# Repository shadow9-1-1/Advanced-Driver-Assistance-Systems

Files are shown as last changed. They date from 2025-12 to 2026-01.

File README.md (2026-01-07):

# Advanced-Driver-Assistance-Systems
Embedded Systems project that required to design and implement common ADAS (Advanced Driver-Assistance Systems) shipped in modern cars and EVs (Electric Vehicles).

---
1) Based on the input from the driver on the acceleration pedal, the microcontroller generates the corresponding output to the motor driving system to move the car. The vehicle speed is displayed on the LCD. When the brake pedal is pressed, the car decelerates until it stops regardless the status of the accelerator pedal. Vehicle system dynamics have to be preserved: no sudden stop. An ultrasonic sensor is used so that the car will decelerate if the TTC (time-to-collision) is less than the time needed to bring a car to halt.

2) Based on the surrounding light, the headlights of the vehicle are turned ON/OFF. An indicator in the LCD shows the status of the vehicle lights.

3) Before starting a trip, the vehicle does a check on seat belts and door locks. The car doesn’t move if any detected occupant doesn’t fasten his belt, or a door is still open.

4) All system parameters should be reported via a Bluetooth connection to a central data logging system.

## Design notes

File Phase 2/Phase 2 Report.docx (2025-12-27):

Advanced Driver-Assistance Systems

SW252 - Course Project – Phase 2

Ahmed Wael 202201415

A. Component List

1. Arduino Uno Rev3 with CH340 Uploader

2. Breadboard 400 points

3. Bluetooth Module HC-05

4. L298 Motor Driver Module

5. 4 DC Geared Motor Dual Shaft 3:6VDC 450 rpm with Wheel (D: 65mm X W: 26mm)

6. HC-SR04 Ultrasonic Wave Detector Sensor 3.3V~5V

7. 4 Li-ion Battery 3.7V Rechargeable (Recycled) 18650-1200mAh

8. Dip Switch 8 Way

9. Photo-resistor LDR Light Sensor Module

10. Character LCD 2x16 Blue with Soldering Serial interface IIC/I2C Module

11. Red LED 5mm

12. Green LED 5mm

B. System architecture schematic

Connections Overview

1. Bluetooth Communication

- HC-05 TX → Arduino Pin 10
- HC-05 RX → Arduino Pin 11
- Used to receive:
  - Movement commands (F, B, L, R, S)
  - Speed levels (0–9, q)
- Used to send report for the connected device about:
  - Speed
  - Distance
  - Safety Status

2. Motor Control (L298 Module)

- ENA (PWM speed control) → Arduino Pin 3
- ENB (PWM speed control) → Arduino Pin 9
- IN1 → Arduino Pin 5
- IN2 → Arduino Pin 4
- IN3 → Arduino Pin 7
- IN4 → Arduino Pin 6

These pins control:

- Forward / backward movement
- Left / right turning
- Smooth acceleration and deceleration using PWM

3. Ultrasonic Sensor (HC-SR04)

- Trig → Arduino Pin 12
- Echo → Arduino Pin 8

Used to:

- Measure distance to obstacles
- Calculate Time-To-Collision (TTC)
- Reduce speed automatically when unsafe

4. Light Detection System

- LDR Output → Arduino A0
- Headlight LED → Arduino Pin 2

If ambient light is low, headlights turn ON automatically.

5. LCD Display (I2C)

- SDA → Arduino A4
- SCL → Arduino A5

Displays:

- Speed value
- Light status
- Obstacle safety state

6. Power Supply

- 4× Li-ion batteries
- Motor driver powered directly
- Arduino powered through regulated input

7. Safety Buttons Sensors

- Seat Belt Sensor → A1

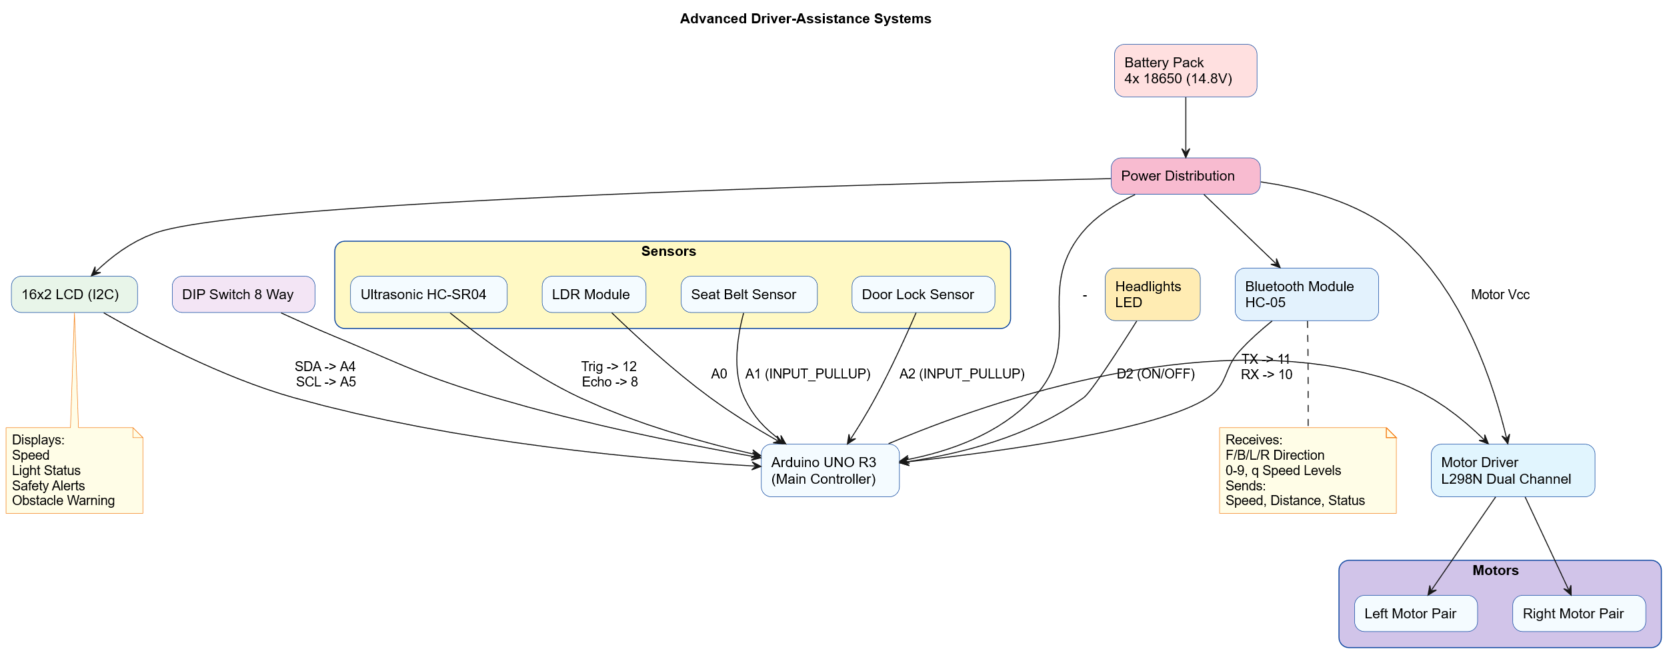
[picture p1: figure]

- Door Lock Sensor → A2

Program Modules with Comments

1. Initialization Module (setup())

- Initialize serial communication
- Initialize Bluetooth
- Initialize LCD
- Configure all I/O pins
- Display startup message

2. Main Control Loop (loop())

- Read Bluetooth command (direction + speed)
- Read LDR for light level
- Read ultrasonic sensor for distance
- Apply incremental speed update
- Perform safety validation
- Execute movement (Forward / Reverse / Turn / Stop)
- Update LCD with system status
- Send Bluetooth telemetry logs

3. Bluetooth Command Processing

- Receives Bluetooth command characters
- Converts characters 0–9 and q into PWM speed values
- Stores target speed in Speed variable
- Does NOT move the car — only updates speed reference
- Send report to the connected device about (speed, light and safety state)

4. Ultrasonic Distance & Safety Module

- Measure obstacle distance
- Calculate Time To Collision (TTC)
- Reduce speed automatically when TTC is unsafe

5. Speed Control Module (Smooth Acceleration)

- Adjust motor speed
- Updates every 40 ms to ensure smooth motion
- Prevent sudden braking
- Uses PWM on ENA and ENB pins

6. Movement Control Module

Command | Action
F | Move forward
B | Move backward
L | Turn left
R | Turn right
S / default | Stop

Motor Direction Logic:
Implemented using IN1–IN4 pin combinations.

7. LDR

- Detect surrounding light
- Turn headlights ON/OFF automatically

8. LCD Display Module

Displays:

- Speed
- Light status (ON/OFF)
- Safety state (SAFE / OBSTACLE)

9. Safety Buttons Sensors

- Check the seatbelt and door before moving
- The car can move if the door is closed and the seatbelt is fastened
- Otherwise, the car will not move.

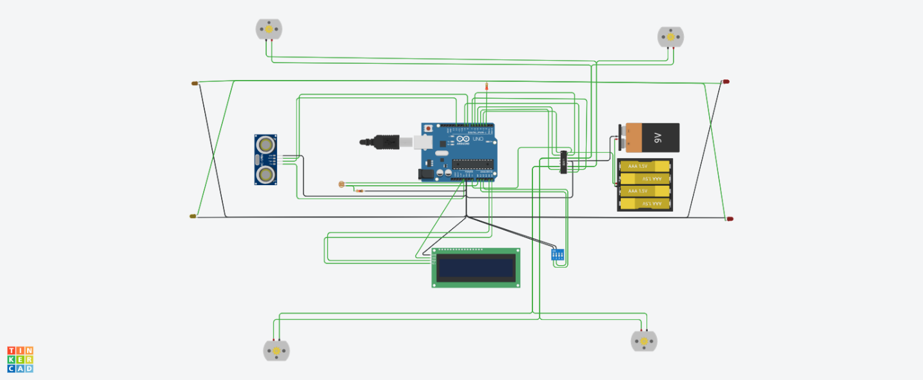
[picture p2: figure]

https://www.tinkercad.com/things/biWAMIYXoqj-phase-1-project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

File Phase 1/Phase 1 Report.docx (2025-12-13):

Advanced Driver-Assistance Systems

SW252 - Course Project – Phase 1

Ahmed Wael 202201415

A. Component List

1. Arduino Uno Rev3 with CH340 Uploader

2. Bluetooth Module HC-05 3. L298 Motor Driver Module

4. DC Geared Motor Dual Shaft 3:6VDC 450 rpm with Wheel (D: 65mm X W: 26mm)

5. HC-SR04 Ultrasonic Wave Detector Sensor 3.3V~5V

6. 4 Li-ion Battery 3.7V Rechargeable (Recycled) 18650-1200mAh

7. Photo-resistor LDR Light Sensor Module

8. Character LCD 2x16 Blue with Soldering Serial interface IIC/I2C Module

9. Red LED 5mm

10. Green LED 5mm

B. System architecture schematic

Connections Overview

1. Bluetooth Communication

- HC-05 TX → Arduino Pin 10
- HC-05 RX → Arduino Pin 11
- Used to receive:
  - Movement commands (F, B, L, R, S)
  - Speed levels (0–9, q)

2. Motor Control (L298 Module)

- ENA (PWM speed control) → Arduino Pin 3
- ENB (PWM speed control) → Arduino Pin 9
- IN1 → Arduino Pin 5
- IN2 → Arduino Pin 4
- IN3 → Arduino Pin 7
- IN4 → Arduino Pin 6

These pins control:

- Forward / backward movement
- Left / right turning
- Smooth acceleration and deceleration using PWM

3. Ultrasonic Sensor (HC-SR04)

- Trig → Arduino Pin 12
- Echo → Arduino Pin 8

Used to:

- Measure distance to obstacles
- Calculate Time-To-Collision (TTC)
- Reduce speed automatically when unsafe

4. Light Detection System

- LDR Output → Arduino A0
- Headlight LED → Arduino Pin 2

If ambient light is low, headlights turn ON automatically.

5. LCD Display (I2C)

- SDA → Arduino A4
- SCL → Arduino A5

Displays:

- Speed value
- Light status
- Obstacle safety state

6. Power Supply

- 4× Li-ion batteries
- Motor driver powered directly
- Arduino powered through regulated input

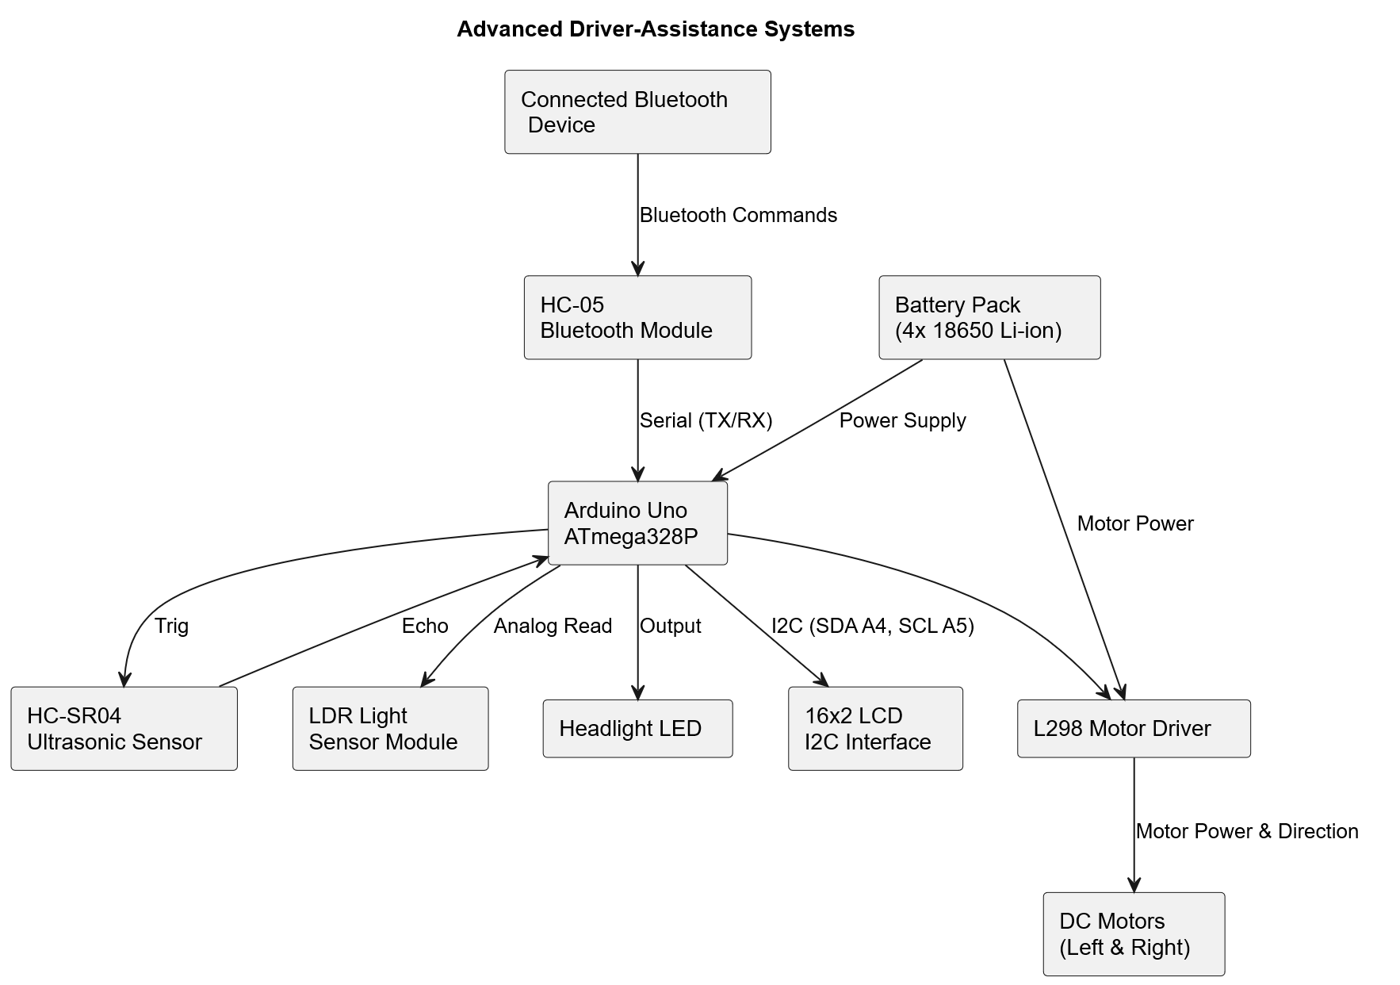
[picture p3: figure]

C. Program Modules with Comments

1. Initialization Module (setup())

- Initialize serial communication
- Initialize Bluetooth
- Initialize LCD
- Configure all I/O pins
- Display startup message

2. Main Control Loop (loop())

- Continuously read inputs
- Apply safety logic
- Control motors
- Update display

3. Bluetooth Command Processing

- Maps Bluetooth characters (0–9, q) to PWM speed values
- Updates target motor speed

4. Ultrasonic Distance & Safety Module

- Measure obstacle distance
- Calculate Time To Collision (TTC)
- Reduce speed automatically when TTC is unsafe

5. Speed Control Module (Smooth Acceleration)

- Gradually adjust motor speed
- Prevent sudden acceleration or braking
- Uses PWM on ENA and ENB pins

6. Movement Control Module

Command | Action
F | Move forward
B | Move backward
L | Turn left
R | Turn right
S / default | Stop

Motor Direction Logic:
Implemented using IN1–IN4 pin combinations.

7. LDR

- Detect surrounding light
- Turn headlights ON/OFF automatically

8. LCD Display Module

Displays:

- Speed
- Light status (ON/OFF)
- Safety state (SAFE / OBSTACLE)

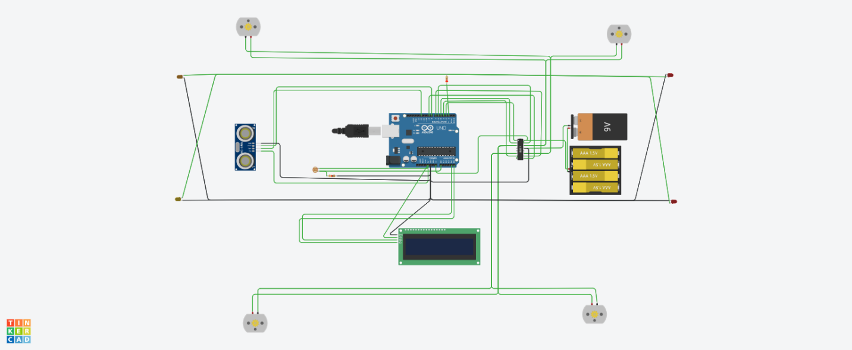
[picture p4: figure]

https://www.tinkercad.com/things/biWAMIYXoqj-phase-1-project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

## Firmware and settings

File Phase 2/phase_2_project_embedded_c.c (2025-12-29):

#define F_CPU 16000000UL

#include <avr/io.h>
#include <avr/interrupt.h>
#include <util/delay.h>
#include <stdint.h>
#include <stdbool.h>
#include <string.h>
#include <stdlib.h>

// pins

// Motor Driver Pins (Port D and Port B)
#define ENA_PIN     PD3     // OC2B - PWM (Arduino D3)
#define ENB_PIN     PB1     // OC1A - PWM (Arduino D9)
#define IN1_PIN     PD5     // Arduino D5
#define IN2_PIN     PD4     // Arduino D4
#define IN3_PIN     PD7     // Arduino D7
#define IN4_PIN     PD6     // Arduino D6

// Ultrasonic Pins
#define TRIG_PIN    PB4     // Arduino D12
#define ECHO_PIN    PB0     // Arduino D8

// Headlight Pin
#define HEADLIGHT_PIN PD2   // Arduino D2

// ADC Channels
#define LDR_CHANNEL         0   // A0
#define SEATBELT_CHANNEL    1   // A1
#define DOORLOCK_CHANNEL    2   // A2

// I2C LCD Address
#define LCD_I2C_ADDR        0x20    // PCF8574 default address (Adafruit uses 0x20)

// ============================================================================
//                          CONSTANTS
// ============================================================================

#define HEADLIGHT_THRESHOLD     400
#define MIN_STOPPING_DISTANCE   25.0f

// TTC Parameters
#define WHEEL_DIAMETER          0.065f      // meters
#define MAX_RPM                 200.0f
#define DECEL_RATE              0.5f        // m/s^2

#ifndef M_PI
#define M_PI 3.14159265358979323846f
#endif

volatile char bt_cmd = 'S';
volatile int target_speed = 0;
volatile int current_speed = 0;
volatile uint32_t millis_counter = 0;

float prev_distance = 400.0f;
uint32_t prev_dist_time = 0;
float approach_velocity = 0.0f;

uint32_t last_update = 0;
uint32_t last_bt_send = 0;


ISR(TIMER0_OVF_vect) {
    millis_counter++;
}

uint32_t millis(void) {
    uint32_t m;
    uint8_t sreg = SREG;
    cli();
    m = millis_counter;
    SREG = sreg;
    return m;
}

void millis_init(void) {
    TCCR0A = 0;
    TCCR0B = (1 << CS01) | (1 << CS00);  // Prescaler 64
    TIMSK0 = (1 << TOIE0);               // Enable overflow interrupt
}

// Bluetooth HC-05)


void uart_init(uint32_t baud) {
    uint16_t ubrr = (F_CPU / 16 / baud) - 1;
    UBRR0H = (uint8_t)(ubrr >> 8);
    UBRR0L = (uint8_t)ubrr;
    UCSR0B = (1 << RXEN0) | (1 << TXEN0) | (1 << RXCIE0);  // Enable RX interrupt
    UCSR0C = (1 << UCSZ01) | (1 << UCSZ00);  // 8-bit data
}

// Circular buffer for received data
#define UART_RX_BUFFER_SIZE 32
volatile char uart_rx_buffer[UART_RX_BUFFER_SIZE];
volatile uint8_t uart_rx_head = 0;
volatile uint8_t uart_rx_tail = 0;

// UART RX Interrupt - stores received bytes in buffer
ISR(USART_RX_vect) {
    char c = UDR0;
    uint8_t next_head = (uart_rx_head + 1) % UART_RX_BUFFER_SIZE;
    if (next_head != uart_rx_tail) {  // Buffer not full
        uart_rx_buffer[uart_rx_head] = c;
        uart_rx_head = next_head;
    }
}

bool uart_available(void) {
    return (uart_rx_head != uart_rx_tail);
}

char uart_read(void) {
    while (!uart_available());  // Wait for data
    char c = uart_rx_buffer[uart_rx_tail];
    uart_rx_tail = (uart_rx_tail + 1) % UART_RX_BUFFER_SIZE;
    return c;
}

char uart_read_nonblocking(void) {
    if (!uart_available()) return 0;
    char c = uart_rx_buffer[uart_rx_tail];
    uart_rx_tail = (uart_rx_tail + 1) % UART_RX_BUFFER_SIZE;
    return c;
}

void uart_putchar(char c) {
    while (!(UCSR0A & (1 << UDRE0)));
    UDR0 = c;
}

void uart_print(const char *str) {
    while (*str) {
        uart_putchar(*str++);
    }
}

void uart_println(const char *str) {
    uart_print(str);
    uart_putchar('\r');
    uart_putchar('\n');
}

void uart_print_int(int val) {
    char buf[12];
    itoa(val, buf, 10);
    uart_print(buf);
}

void uart_print_float(float val, uint8_t decimals) {
    char buf[16];
    dtostrf(val, 0, decimals, buf);
    uart_print(buf);
}

// ============================================================================
//                          I2C (TWI) INTERFACE
// ============================================================================

#define I2C_FREQ    100000UL

void i2c_init(void) {
    // Set SCL frequency
    TWSR = 0;  // Prescaler = 1
    TWBR = ((F_CPU / I2C_FREQ) - 16) / 2;
    TWCR = (1 << TWEN);  // Enable TWI
}

void i2c_start(void) {
    TWCR = (1 << TWINT) | (1 << TWSTA) | (1 << TWEN);
    while (!(TWCR & (1 << TWINT)));
}

void i2c_stop(void) {
    TWCR = (1 << TWINT) | (1 << TWSTO) | (1 << TWEN);
    while (TWCR & (1 << TWSTO));
}

void i2c_write(uint8_t data) {
    TWDR = data;
    TWCR = (1 << TWINT) | (1 << TWEN);
    while (!(TWCR & (1 << TWINT)));
}

// ============================================================================
//                          LCD (I2C via PCF8574)
// ============================================================================

// PCF8574 bit mapping for LCD
#define LCD_RS      0x01
#define LCD_RW      0x02
#define LCD_EN      0x04
#define LCD_BL      0x08    // Backlight
#define LCD_D4      0x10
#define LCD_D5      0x20
#define LCD_D6      0x40
#define LCD_D7      0x80

static uint8_t lcd_backlight = LCD_BL;

void lcd_write_nibble(uint8_t nibble, uint8_t rs) {
    uint8_t data = (nibble & 0xF0) | lcd_backlight;
    if (rs) data |= LCD_RS;
    
    i2c_start();
    i2c_write(LCD_I2C_ADDR << 1);
    
    // Enable high
    i2c_write(data | LCD_EN);
    _delay_us(1);
    
    // Enable low
    i2c_write(data & ~LCD_EN);
    _delay_us(50);
    
    i2c_stop();
}

void lcd_write_byte(uint8_t byte, uint8_t rs) {
    lcd_write_nibble(byte & 0xF0, rs);
    lcd_write_nibble((byte << 4) & 0xF0, rs);
}

void lcd_command(uint8_t cmd) {
    lcd_write_byte(cmd, 0);
    if (cmd < 4) _delay_ms(2);  // Clear/Home commands need more time
}

void lcd_data(uint8_t data) {
    lcd_write_byte(data, 1);
}

void lcd_init(void) {
    _delay_ms(50);
    
    // 4-bit initialization sequence
    lcd_write_nibble(0x30, 0);
    _delay_ms(5);
    lcd_write_nibble(0x30, 0);
    _delay_us(150);
    lcd_write_nibble(0x30, 0);
    _delay_us(150);
    lcd_write_nibble(0x20, 0);  // 4-bit mode
    _delay_us(150);
    
    lcd_command(0x28);  // 4-bit, 2 lines, 5x8 font
    lcd_command(0x0C);  // Display on, cursor off
    lcd_command(0x06);  // Entry mode: increment
    lcd_command(0x01);  // Clear display
    _delay_ms(2);
}

void lcd_clear(void) {
    lcd_command(0x01);
    _delay_ms(2);
}

void lcd_set_cursor(uint8_t col, uint8_t row) {
    uint8_t addr = col + (row == 0 ? 0x00 : 0x40);
    lcd_command(0x80 | addr);
}

void lcd_print(const char *str) {
    while (*str) {
        lcd_data(*str++);
    }
}

void lcd_print_int(int val) {
    char buf[12];
    itoa(val, buf, 10);
    lcd_print(buf);
}

// ============================================================================
//                          ADC
// ============================================================================

void adc_init(void) {
    // AVCC reference, right adjust
    ADMUX = (1 << REFS0);
    // Enable ADC, prescaler 128 (125kHz ADC clock at 16MHz)
    ADCSRA = (1 << ADEN) | (1 << ADPS2) | (1 << ADPS1) | (1 << ADPS0);
}

uint16_t adc_read(uint8_t channel) {
    ADMUX = (ADMUX & 0xF0) | (channel & 0x0F);
    ADCSRA |= (1 << ADSC);              // Start conversion
    while (ADCSRA & (1 << ADSC));       // Wait for completion
    return ADC;
}

// ============================================================================
//                          PWM (Timer1 and Timer2)
// ============================================================================

void pwm_init(void) {
    // Timer2 for ENA (PD3/OC2B) - Fast PWM
    TCCR2A = (1 << COM2B1) | (1 << WGM21) | (1 << WGM20);
    TCCR2B = (1 << CS21);  // Prescaler 8
    OCR2B = 0;
    
    // Timer1 for ENB (PB1/OC1A) - Fast PWM 8-bit
    TCCR1A = (1 << COM1A1) | (1 << WGM10);
    TCCR1B = (1 << WGM12) | (1 << CS11);  // Prescaler 8
    OCR1A = 0;
}

void pwm_set_ena(uint8_t duty) {
    OCR2B = duty;
}

void pwm_set_enb(uint8_t duty) {
    OCR1A = duty;
}

// ============================================================================
//                          GPIO INITIALIZATION
// ============================================================================

void gpio_init(void) {
    // Motor control pins as outputs
    DDRD |= (1 << ENA_PIN) | (1 << IN1_PIN) | (1 << IN2_PIN) | 
            (1 << IN3_PIN) | (1 << IN4_PIN) | (1 << HEADLIGHT_PIN);
    DDRB |= (1 << ENB_PIN) | (1 << TRIG_PIN);
    
    // Echo pin as input
    DDRB &= ~(1 << ECHO_PIN);
    
    // ADC pins (A0, A1, A2) - configured by ADC init
    // Enable internal pullups for safety sensors
    PORTC |= (1 << PC1) | (1 << PC2);
}

// ============================================================================
//                          ULTRASONIC SENSOR
// ============================================================================

float get_distance(void) {
    // Send trigger pulse
    PORTB &= ~(1 << TRIG_PIN);
    _delay_us(2);
    PORTB |= (1 << TRIG_PIN);
    _delay_us(10);
    PORTB &= ~(1 << TRIG_PIN);
    
    // Wait for echo start (with timeout)
    uint16_t timeout = 10000;
    while (!(PINB & (1 << ECHO_PIN)) && timeout--) {
        _delay_us(1);
    }
    if (timeout == 0) return 400.0f;
    
    // Measure echo duration
    uint32_t duration = 0;
    timeout = 20000;
    while ((PINB & (1 << ECHO_PIN)) && timeout--) {
        duration++;
        _delay_us(1);
    }
    if (timeout == 0) return 400.0f;
    
    // Calculate distance in cm
    float distance = (float)duration * 0.034f / 2.0f;
    if (distance > 400.0f) distance = 400.0f;
    
    return distance;
}

// ============================================================================
//                          TTC SYSTEM
// ============================================================================

float pwm_to_velocity(int pwm_value) {
    float rpm = ((float)pwm_value / 255.0f) * MAX_RPM;
    float wheel_circumference = M_PI * WHEEL_DIAMETER;
    float velocity = (rpm * wheel_circumference) / 60.0f;
    return velocity;
}

void calculate_approach_velocity(float current_dist) {
    uint32_t current_time = millis();
    uint32_t delta_time = current_time - prev_dist_time;
    
    if (delta_time >= 50) {
        float dist_change = (prev_distance - current_dist) / 100.0f;
        float time_sec = (float)delta_time / 1000.0f;
        
        if (time_sec > 0) {
            float new_velocity = dist_change / time_sec;
            approach_velocity = 0.7f * approach_velocity + 0.3f * new_velocity;
        }
        
        prev_distance = current_dist;
        prev_dist_time = current_time;
    }
}

int calculate_ttc_speed(float distance, int target_spd) {
    float dist_meters = distance / 100.0f;
    float car_velocity = pwm_to_velocity(current_speed);
    float closing_velocity = car_velocity + approach_velocity;
    
    if (closing_velocity <= 0.01f) {
        return target_spd;
    }
    
    float ttc = dist_meters / closing_velocity;
    float time_to_stop = car_velocity / DECEL_RATE;
    float stopping_distance = (car_velocity * car_velocity) / (2.0f * DECEL_RATE);
    
    float safety_margin = 1.5f;
    float required_ttc = time_to_stop * safety_margin;
    float required_distance = stopping_distance * safety_margin * 100.0f;
    
    if (ttc < required_ttc || distance < required_distance) {
        float ttc_ratio = ttc / required_ttc;
        float dist_ratio = distance / required_distance;
        
        float ratio = (ttc_ratio < dist_ratio) ? ttc_ratio : dist_ratio;
        if (ratio < 0.0f) ratio = 0.0f;
        if (ratio > 1.0f) ratio = 1.0f;
        
        int new_speed = (int)((float)target_spd * ratio);
        
        if (distance < MIN_STOPPING_DISTANCE) {
            return 0;
        }
        return (new_speed > 0) ? new_speed : 0;
    }
    
    return target_spd;
}

// ============================================================================
//                          SAFETY CHECK
// ============================================================================

bool safety_ok(void) {
    // Read with digital threshold (>512 = HIGH with pullup means OK)
    uint16_t belt = adc_read(SEATBELT_CHANNEL);
    uint16_t door = adc_read(DOORLOCK_CHANNEL);
    
    bool belt_ok = (belt > 512);
    bool door_ok = (door > 512);
    
    return (belt_ok && door_ok);
}

// ============================================================================
//                          SPEED COMMAND HANDLER
// ============================================================================

void handle_speed_command(char cmd) {
    switch (cmd) {
        case '0': target_speed = 80;  break;
        case '1': target_speed = 100; break;
        case '2': target_speed = 120; break;
        case '3': target_speed = 140; break;
        case '4': target_speed = 160; break;
        case '5': target_speed = 180; break;
        case '6': target_speed = 200; break;
        case '7': target_speed = 220; break;
        case '8': target_speed = 240; break;
        case '9': target_speed = 255; break;
        case 'q': target_speed = 255; break;
        default: break;
    }
}

// ============================================================================
//                          SPEED UPDATE
// ============================================================================

void update_speed(int target) {
    if (millis() - last_update < 40) return;
    last_update = millis();
    
    if (current_speed < target) current_speed += 5;
    else if (current_speed > target) current_speed -= 5;
    
    if (current_speed < 0) current_speed = 0;
    if (current_speed > 255) current_speed = 255;
    
    pwm_set_ena((uint8_t)current_speed);
    pwm_set_enb((uint8_t)current_speed);
}

// ============================================================================
//                          MOTOR CONTROL
// ============================================================================

void motor_forward(void) {
    PORTD &= ~(1 << IN1_PIN);
    PORTD |= (1 << IN2_PIN);
    PORTD &= ~(1 << IN3_PIN);
    PORTD |= (1 << IN4_PIN);
}

void motor_backward(void) {
    PORTD |= (1 << IN1_PIN);
    PORTD &= ~(1 << IN2_PIN);
    PORTD |= (1 << IN3_PIN);
    PORTD &= ~(1 << IN4_PIN);
}

void motor_left(void) {
    PORTD |= (1 << IN1_PIN);
    PORTD &= ~(1 << IN2_PIN);
    PORTD &= ~(1 << IN3_PIN);
    PORTD |= (1 << IN4_PIN);
}

void motor_right(void) {
    PORTD &= ~(1 << IN1_PIN);
    PORTD |= (1 << IN2_PIN);
    PORTD |= (1 << IN3_PIN);
    PORTD &= ~(1 << IN4_PIN);
}

void motor_stop(void) {
    PORTD &= ~((1 << IN1_PIN) | (1 << IN2_PIN) | (1 << IN3_PIN) | (1 << IN4_PIN));
}

void move_car(char cmd) {
    switch (cmd) {
        case 'F': motor_forward();  break;
        case 'B': motor_backward(); break;
        case 'L': motor_left();     break;
        case 'R': motor_right();    break;
        default:  motor_stop();     break;
    }
}

// ============================================================================
//                          LCD UPDATE
// ============================================================================

void update_lcd(int spd, bool light_on, float dist, bool safe) {
    lcd_set_cursor(0, 0);
    lcd_print("SPD:");
    if (spd < 100) lcd_print(" ");
    if (spd < 10) lcd_print(" ");
    lcd_print_int(spd);
    
    lcd_print(" L:");
    lcd_print(light_on ? "ON " : "OFF");
    
    lcd_set_cursor(0, 1);
    if (!safe) {
        lcd_print("SAFETY FAIL    ");
    } else if (dist < MIN_STOPPING_DISTANCE) {
        lcd_print("EMERG STOP!    ");
    } else if (current_speed < target_speed && bt_cmd == 'F') {
        lcd_print("TTC BRAKING    ");
    } else {
        lcd_print("D:");
        lcd_print_int((int)dist);
        lcd_print("cm SAFE   ");
    }
}

// ============================================================================
//                    BLUETOOTH DATA LOGGING
// ============================================================================

void send_bluetooth_log(bool light_on, float dist, bool safe) {
    if (millis() - last_bt_send < 500) return;
    last_bt_send = millis();
    
    uart_print("SPD=");
    uart_print_int(current_speed);
    uart_println("");
    
    uart_print("TARGET_SPD=");
    uart_print_int(target_speed);
    uart_println("");
    
    uart_print("LIGHT=");
    uart_println(light_on ? "ON" : "OFF");
    
    uart_print("DIST=");
    uart_print_float(dist, 1);
    uart_println("");
    
    uart_print("APPROACH_VEL=");
    uart_print_float(approach_velocity, 3);
    uart_println("");
    
    uart_print("TTC_ACTIVE=");
    uart_println((current_speed < target_speed && bt_cmd == 'F') ? "YES" : "NO");
    
    uart_print("SAFETY=");
    uart_println(safe ? "OK" : "FAIL");
    
    uart_print("CMD=");
    char cmd_str[2] = {bt_cmd, '\0'};
    uart_println(cmd_str);
    
    uart_println("---");  // Separator for readability
}

// ============================================================================
//                          MAIN FUNCTION
// ============================================================================

int main(void) {
    // Initialize peripherals
    gpio_init();
    uart_init(9600);      // Hardware UART for Bluetooth
    i2c_init();
    adc_init();
    pwm_init();
    millis_init();
    
    // Enable global interrupts
    sei();
    
    // Initialize LCD
    lcd_init();
    lcd_print("   SMART  CAR");
    lcd_set_cursor(0, 1);
    lcd_print("   By Shadow");
    _delay_ms(1500);
    lcd_clear();
    
    uart_println("Smart Car Ready");
    uart_println("Send F/B/L/R/S to move");
    uart_println("Send 0-9 for speed");
    
    // Main loop
    while (1) {
        // Check for Bluetooth commands (using hardware UART with interrupt buffer)
        if (uart_available()) {
            char received = uart_read_nonblocking();
            if (received != 0) {
                bt_cmd = received;
                
                // Echo back received command
                uart_print("CMD: ");
                char cmd_str[2] = {bt_cmd, '\0'};
                uart_println(cmd_str);
                
                handle_speed_command(bt_cmd);
            }
        }
        
        // Light control by LDR
        uint16_t light_level = adc_read(LDR_CHANNEL);
        bool light_on = (light_level > HEADLIGHT_THRESHOLD);
        if (light_on) {
            PORTD |= (1 << HEADLIGHT_PIN);
        } else {
            PORTD &= ~(1 << HEADLIGHT_PIN);
        }
        
        // Get ultrasonic distance
        float dist = get_distance();
        
        // Calculate approach velocity
        calculate_approach_velocity(dist);
        
        // TTC-based speed adjustment
        int adjusted_speed = target_speed;
        
        if (bt_cmd == 'F') {
            adjusted_speed = calculate_ttc_speed(dist, target_speed);
        }
        
        // Update speed
        update_speed(adjusted_speed);
        
        // Safety check
        bool allowed = safety_ok();
        
        // Movement control
        if (allowed) {
            if (bt_cmd == 'F' && dist < MIN_STOPPING_DISTANCE) {
                motor_stop();
            } else {
                move_car(bt_cmd);
            }
        } else {
            motor_stop();
        }
        
        // Update LCD
        update_lcd(current_speed, light_on, dist, allowed);
        
        // Send Bluetooth log
        send_bluetooth_log(light_on, dist, allowed);
    }
    
    return 0;
}

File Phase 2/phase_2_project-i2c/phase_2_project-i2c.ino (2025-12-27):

#include <SoftwareSerial.h>
#include <Adafruit_LiquidCrystal.h>

// ---------------- LCD (I2C MODE) ----------------
Adafruit_LiquidCrystal lcd(0);  
// SDA → A4 , SCL → A5

// ---------------- BLUETOOTH HC-05 ----------------
SoftwareSerial BT(10, 11);  // TX, RX

// ---------------- MOTOR DRIVER PINS --------------
int ENA = 3;
int ENB = 9;
int IN1 = 5;
int IN2 = 4;
int IN3 = 7;
int IN4 = 6;

// ---------------- ULTRASONIC PINS ----------------
int trigPin = 12;
int echoPin = 8;

// ---------------- LDR (LIGHT SENSOR) -------------
int LDR = A0;    

// ---------------- HEADLIGHT PIN ------------------
int headlights = 2;   

// ---------------- SAFETY SENSORS -----------------
int seatBeltSensor = A1;     
int doorLockSensor = A2;

// ---------------- VARIABLES ----------------------
char btCmd = 'S';
int Speed = 0;
int currentSpeed = 0;
unsigned long lastUpdate = 0;

// Bluetooth logging timer
unsigned long lastBTsend = 0;

// LDR threshold
const int headlightThreshold = 400;

// ---------------- TTC COLLISION AVOIDANCE --------
// Vehicle dynamics parameters
const float wheelDiameter = 0.065;      // meters (65mm typical for small robot car)
const float maxRPM = 200.0;             // max motor RPM at PWM 255
const float decelRate = 0.5;            // deceleration rate in m/s^2 (gradual braking)
const float minStoppingDistance = 5.0;  // minimum safe distance in cm

// Previous distance for velocity calculation
float prevDistance = 400.0;
unsigned long prevDistTime = 0;
float approachVelocity = 0.0;  // relative closing velocity in m/s


// =================================================
//                SETUP
// =================================================
void setup() {
  Serial.begin(9600);
  BT.begin(9600);

  lcd.begin(16, 2);
  lcd.print("   SMART  CAR");
  lcd.setCursor(0, 1);
  lcd.print("   By Shadow");
  delay(1500);
  lcd.clear();

  pinMode(ENA, OUTPUT);
  pinMode(ENB, OUTPUT);
  pinMode(IN1, OUTPUT);
  pinMode(IN2, OUTPUT);
  pinMode(IN3, OUTPUT);
  pinMode(IN4, OUTPUT);

  pinMode(trigPin, OUTPUT);
  pinMode(echoPin, INPUT);

  pinMode(headlights, OUTPUT);

  pinMode(seatBeltSensor, INPUT_PULLUP);
  pinMode(doorLockSensor, INPUT_PULLUP);
}



// =================================================
//                MAIN LOOP
// =================================================
void loop() {

  // ------------ Bluetooth Commands -----------------
  if (BT.available()) {
    btCmd = BT.read();
    Serial.print("CMD: ");
    Serial.println(btCmd);
    handleSpeedCommand(btCmd);
  }

  // ------------ Light Control by LDR ---------------
  int lightLevel = analogRead(LDR);
  bool lightOn = (lightLevel > headlightThreshold);
  digitalWrite(headlights, lightOn ? HIGH : LOW);

  // ------------ Ultrasonic Distance ----------------
  float dist = getDistance();

  // ------------ Calculate Approach Velocity --------
  calculateApproachVelocity(dist);

  // ------------ TTC-based Speed Adjustment ---------
  int adjustedSpeed = Speed;
  bool ttcWarning = false;
  
  if (btCmd == 'F') {
    adjustedSpeed = calculateTTCSpeed(dist, Speed);
    ttcWarning = (adjustedSpeed < Speed);
  }

  // ------------ UPDATE SPEED -----------------------
  updateSpeed(adjustedSpeed);

  // ------------ SAFETY CHECK -----------------------
  bool allowed = safetyOK();

  // ------------ Movement ---------------------------
  if (allowed) {
    
    // TTC system handles gradual deceleration - only full stop at minimum distance
    if (btCmd == 'F' && dist < minStoppingDistance) {
      stopCar();
    } else {
      moveCar(btCmd);
    }

  } else {
    stopCar();
  }

  // ------------ LCD -------------------------------
  updateLCD(currentSpeed, lightOn, dist, allowed);

  // ------------ Bluetooth Logging -----------------
  sendBluetoothLog(lightOn, dist, allowed);
}



// =================================================
//           SAFETY (SEATBELT & DOOR)
// =================================================
bool safetyOK() {
  bool beltOK = digitalRead(seatBeltSensor);  
  bool doorOK = digitalRead(doorLockSensor);  

  if (!beltOK || !doorOK)
    return false;

  return true;
}



// =================================================
//           BLUETOOTH SPEED CONTROL
// =================================================
void handleSpeedCommand(char cmd) {
  switch (cmd) {
    case '0': Speed = 80; break;
    case '1': Speed = 100; break;
    case '2': Speed = 120; break;
    case '3': Speed = 140; break;
    case '4': Speed = 160; break;
    case '5': Speed = 180; break;
    case '6': Speed = 200; break;
    case '7': Speed = 220; break;
    case '8': Speed = 240; break;
    case '9': Speed = 255; break;
    case 'q': Speed = 255; break;
  }
}



// =================================================
//                ULTRASONIC
// =================================================
float getDistance() {
  digitalWrite(trigPin, LOW);
  delayMicroseconds(2);

  digitalWrite(trigPin, HIGH);
  delayMicroseconds(10);
  digitalWrite(trigPin, LOW);

  long duration = pulseIn(echoPin, HIGH, 20000); 
  if (duration == 0) return 400;

  float d = duration * 0.034 / 2.0;
  if (d > 400) d = 400;

  return d;
}



// =================================================
//        TTC (TIME-TO-COLLISION) SYSTEM
// =================================================

// Convert PWM speed to actual velocity in m/s
float pwmToVelocity(int pwmValue) {
  // Linear approximation: PWM 0-255 maps to 0-maxRPM
  float rpm = (pwmValue / 255.0) * maxRPM;
  float wheelCircumference = PI * wheelDiameter;  // meters
  float velocity = (rpm * wheelCircumference) / 60.0;  // m/s
  return velocity;
}

// Calculate approach velocity (how fast obstacle is getting closer)
void calculateApproachVelocity(float currentDist) {
  unsigned long currentTime = millis();
  unsigned long deltaTime = currentTime - prevDistTime;
  
  if (deltaTime >= 50) {  // Update every 50ms for stability
    // Distance change in meters (convert from cm)
    float distChange = (prevDistance - currentDist) / 100.0;
    float timeSec = deltaTime / 1000.0;
    
    if (timeSec > 0) {
      // Positive value means obstacle is getting closer
      float newVelocity = distChange / timeSec;
      // Apply low-pass filter for smooth readings
      approachVelocity = 0.7 * approachVelocity + 0.3 * newVelocity;
    }
    
    prevDistance = currentDist;
    prevDistTime = currentTime;
  }
}
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

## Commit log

2025-12-03 Add circuit diagram to the repo
    [project phase 1.fzz]
2025-12-05 Add phase 1 smart car project files
    Added Arduino source code (phase_1_project1.ino), a Fritzing circuit diagram, and a PNG schematic for the phase 1 smart car project. The code includes Bluetooth control, motor driver logic, ultrasoni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
    [project phase 1.fzz]
2025-12-09 Add Arduino code for smart car control system
    Initial commit of phase1code.ino implementing Bluetooth-based speed and direction control, ultrasonic obstacle detection with TTC safety, LDR-based headlight automation, and LCD status display for a 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
2025-12-24 Phase 2 Startup - lcd i2c
2025-12-29 Increase min stopping distance and add embedded C version
    Raised the minimum safe stopping distance from 5.0 cm to 25.0 cm in the Arduino I2C project. Added a new embedded C implementation for the smart car project, including motor control, safety checks, B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
